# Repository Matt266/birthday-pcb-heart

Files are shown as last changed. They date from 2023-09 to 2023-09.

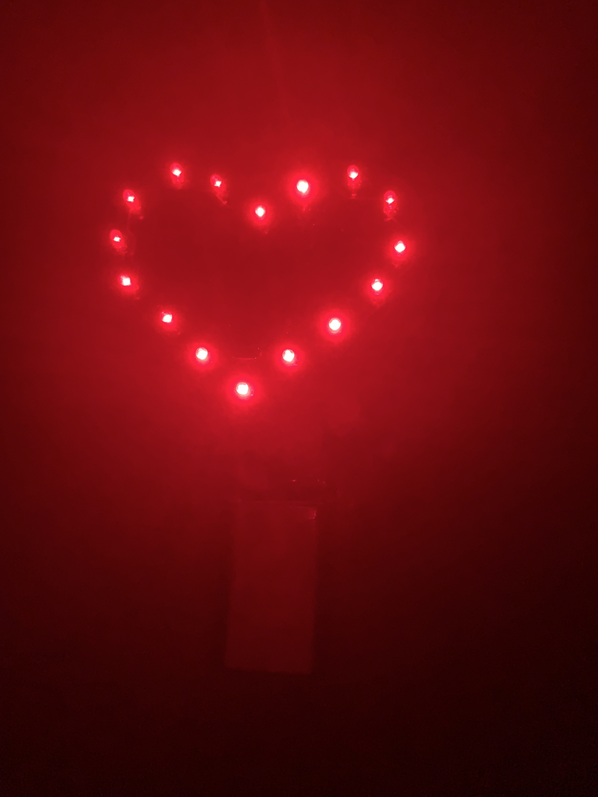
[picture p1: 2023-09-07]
Herz_Leuchten.jpg

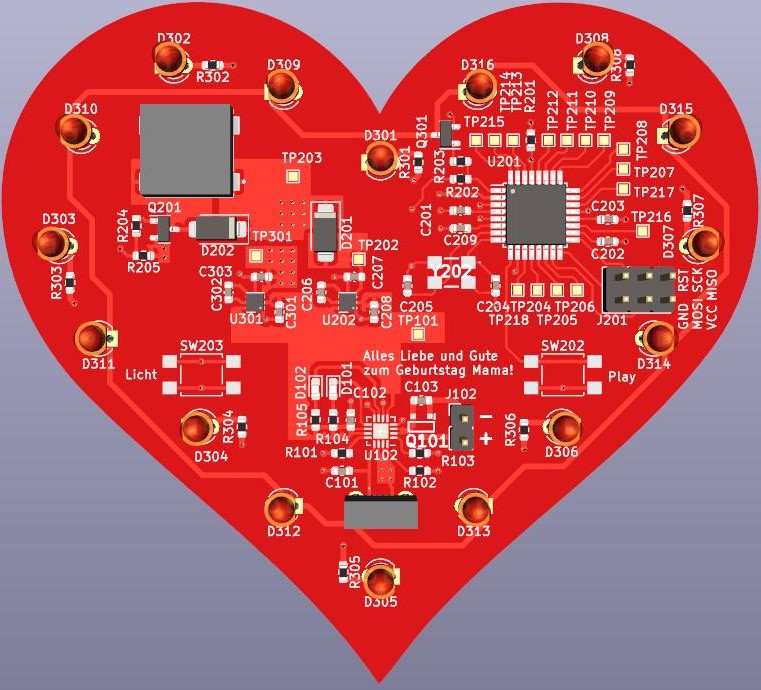
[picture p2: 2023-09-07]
MamaGeburtstag2023_3D.jpg

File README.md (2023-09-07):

# PCB Heart As Birthday Present

As birthday present for our mother my brother and I decided to create a heart-shaped PCB with a buzzer
to play "happy birthday" and LEDs to look pretty. It also should be powered by battery.

Two buttons allow cycling through brightness levels and to initiate the "happy birthday".  

<br>finished PCB<br>

## The Circuit

The exact partnumbers can be taken from the BOM and the KiCAD project. I decided to make use of a LiPo-battery for
the lower self discharge, higher capacity and possibility to recharge in comparison to regular batteries. 

A battery management ic controls charging and allowed me to add an usb connector as charging port. The PCB is also 
powered during charging. A P-Channel MOSFET protects the circuit for reverse polarity on the LiPo-Input. 

Two charge pumps step up the voltage to 5V. This made it Arduino compatible so I could more easily use an Arduino as
in circuit programmer. Also it kept the circuit smaller than inductor based boost-converter. This helped fitting all
components within the heart shape. 

The LEDs and the buzzer are controlled via N-Channel MOSFETs (one for all LEDs one for the buzzer) and connected to
PWM capable pins on the MCU.

To make it more Arduino capable and therefore ease programming for my brother I chose the classic Atmega328p as MCU. 
It was his first time programming something embedded and he did a great job! :)

## The Software

The Software was completely written by my brother (TODO: add Sketch to this repo).

## The Problems

As with all projetcs there are some things that I could have done better in the hindsight.

First of all I didn't include a switch on the PCB. I added one external switch between the LiPO-battery
and PCB afterwards but that isn't nearly as comfortable as having it included directly on the PCB.

The second problem are the charge pumps. While they get the job done they heave a massive quiescent current
and aren't really efficient.  Also running the MCU from a 5V supply voltage increased its power consumption in comparison to e.g. 3.3V.
As the voltage is stepped up the current drawn from the battery inceases even further.
This combination is responsble for a large standby current of 50mA. This massive quiescent current even makes it
unnecessary to consider putting the MCU sleeping. The current draw would remain high nonetheless.

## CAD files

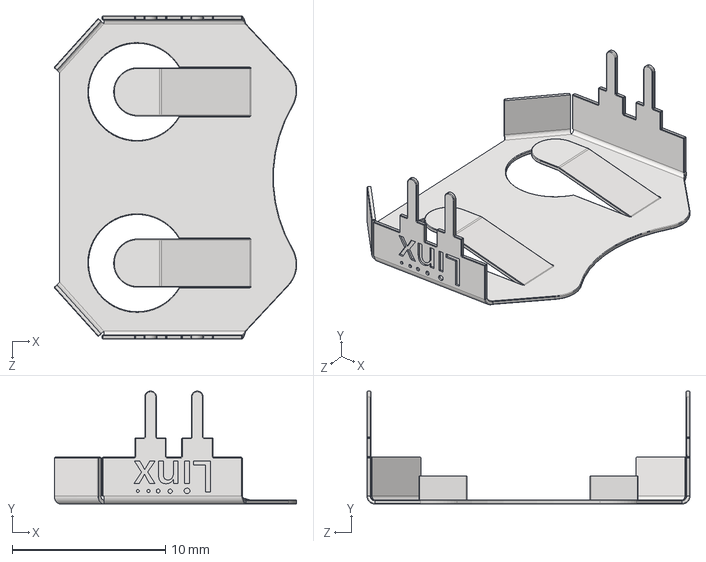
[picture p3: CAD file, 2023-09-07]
LIB_BAT-HLD-001-THM/BAT-HLD-001-THM/3D/BAT-HLD-001-THM.stp
15.8 x 7.37 x 21.1 mm

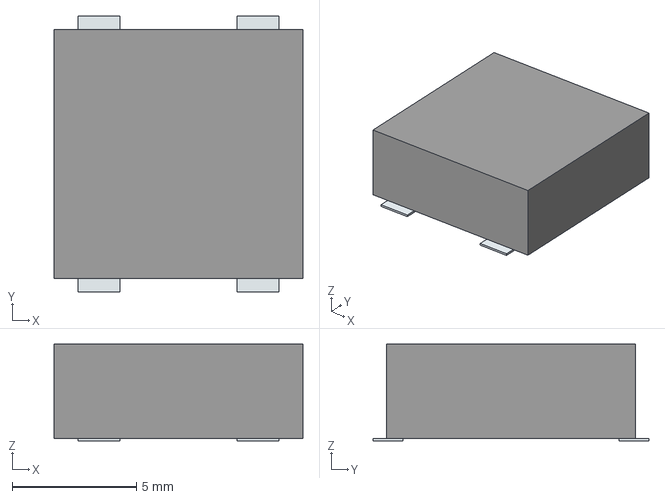
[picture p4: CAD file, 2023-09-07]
LIB_CMT-1032-85-SMT-TR/CMT-1032-85-SMT-TR/3D/CMT-1032-85-SMT-TR.stp
10.0 x 11.1 x 3.90 mm
Pins

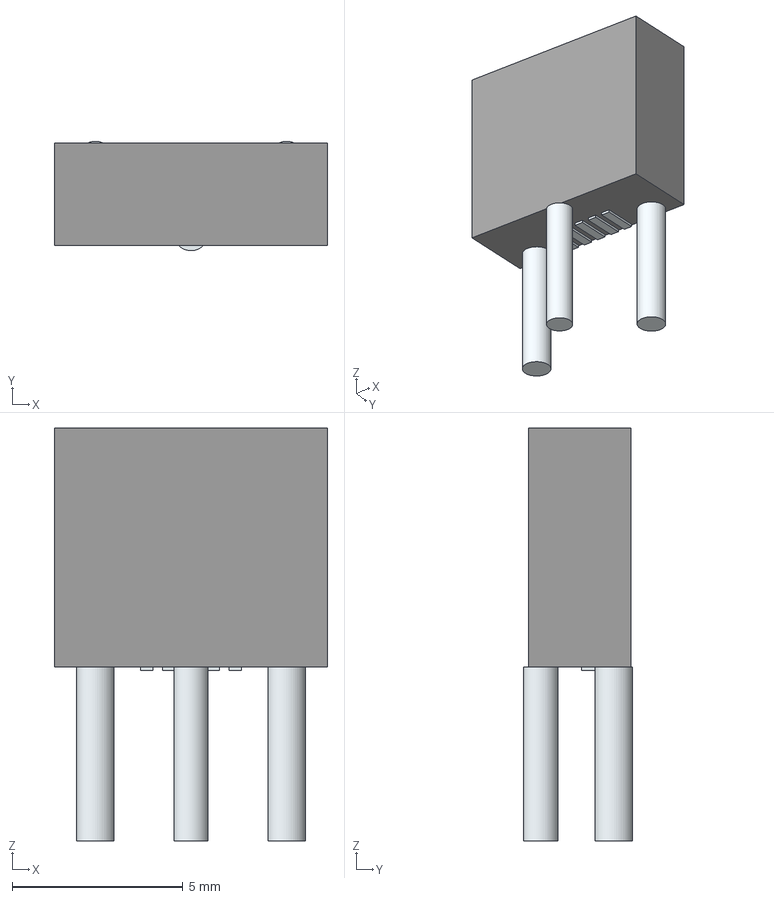
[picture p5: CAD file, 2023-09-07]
LIB_GMCB05B11124H1EU/GMCB05B11124H1EU/3D/GMCB05B11124H1EU.stp
8.00 x 3.20 x 12.1 mm
Pins
Leads

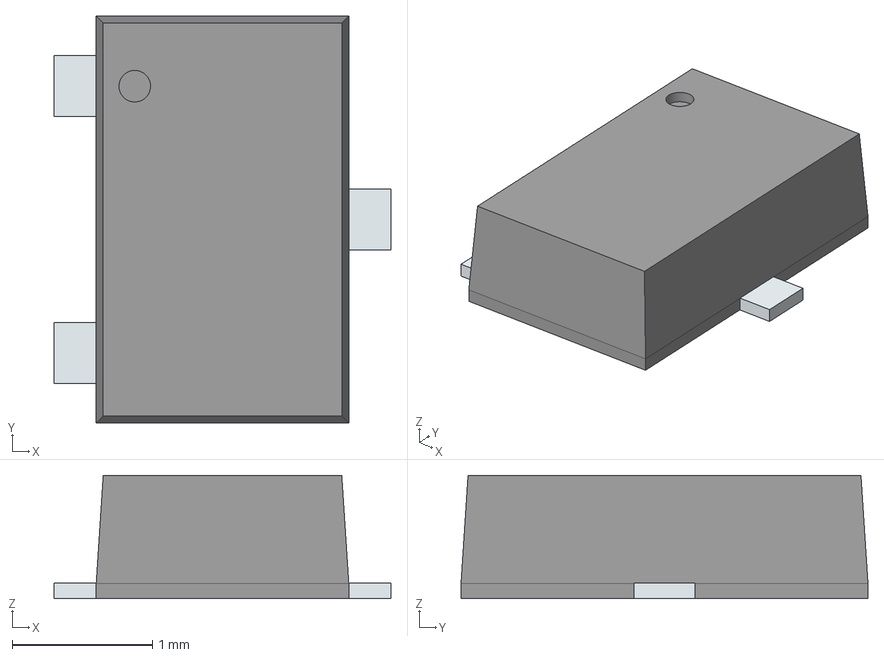
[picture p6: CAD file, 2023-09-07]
LIB_SSM3J358R,LF/SSM3J358R,LF/3D/SSM3J358R,LF.stp
2.40 x 2.90 x 0.878 mm
PinsArrayL
PinsArrayR

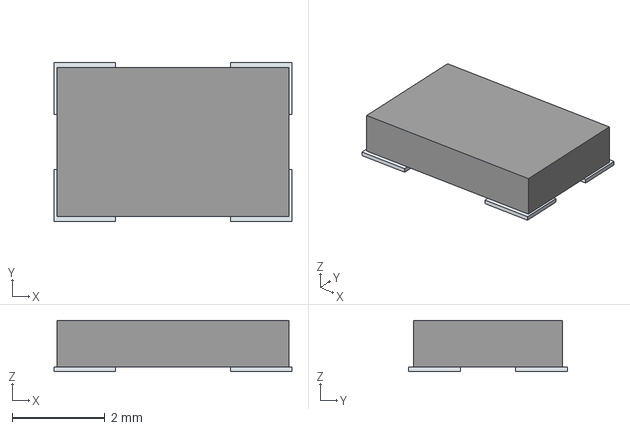
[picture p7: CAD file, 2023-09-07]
LIB_830030819/830030819/3D/830030819.stp
5.12 x 3.42 x 1.10 mm
Pins

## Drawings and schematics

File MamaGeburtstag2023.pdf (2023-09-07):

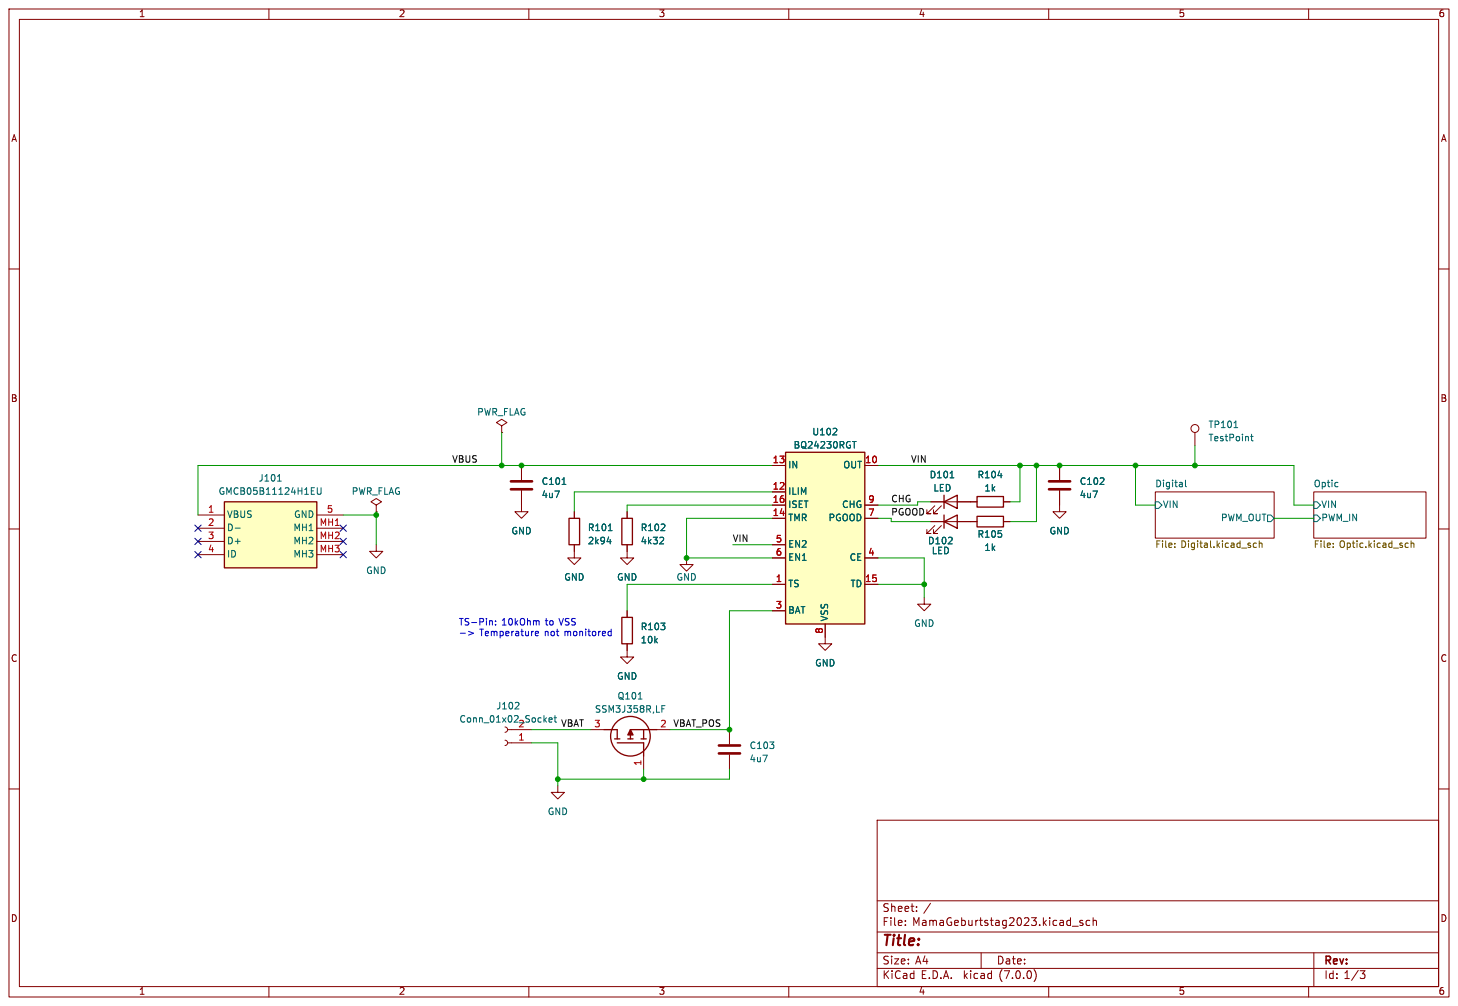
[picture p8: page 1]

PWM_IN Optic File: Optic.kicad_sch PWM_OUT VIN

TS-Pin: 10kOhm to VSS

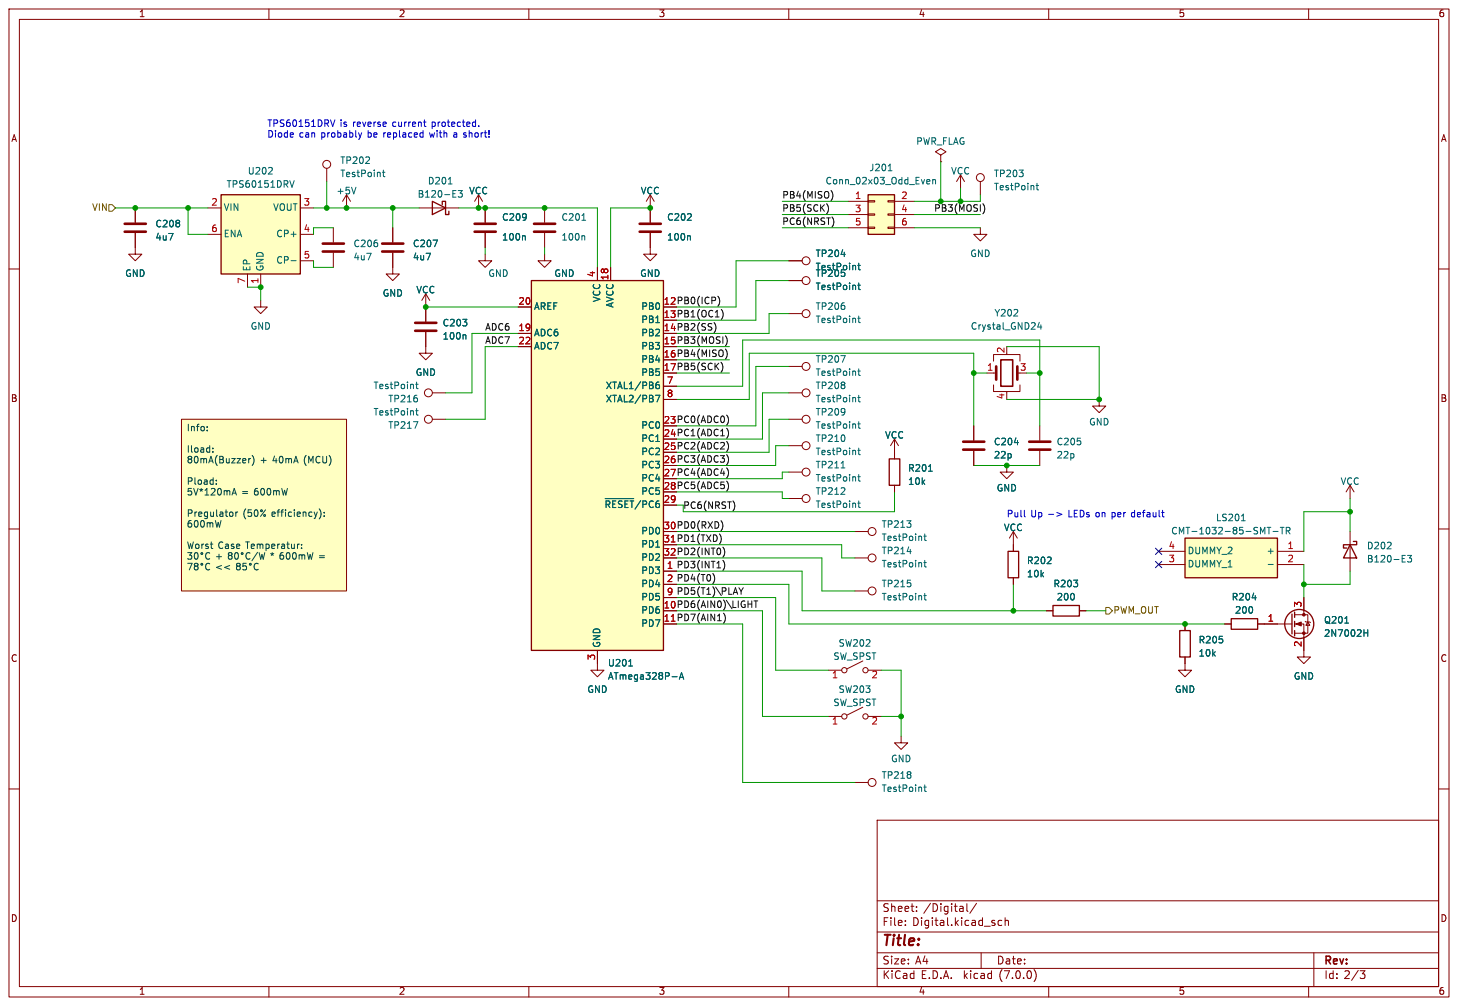
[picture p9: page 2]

1 VIN 2 VOUT 3 CP+ 4 CP- 5 ENA 6 EP

TP210 TestPoint TP211 TestPoint TP212 TestPoint GND

Id: 2/3 Title: File: Digital.kicad_sch Sheet: /Digital/

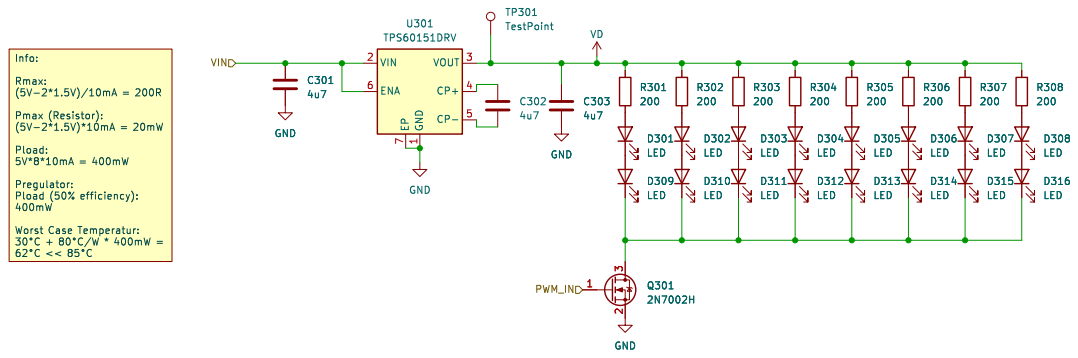
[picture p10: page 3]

1 VIN 2 VOUT 3 CP+ 4 CP- 5 ENA 6 EP

Id: 3/3 Title: File: Optic.kicad_sch Sheet: /Optic/

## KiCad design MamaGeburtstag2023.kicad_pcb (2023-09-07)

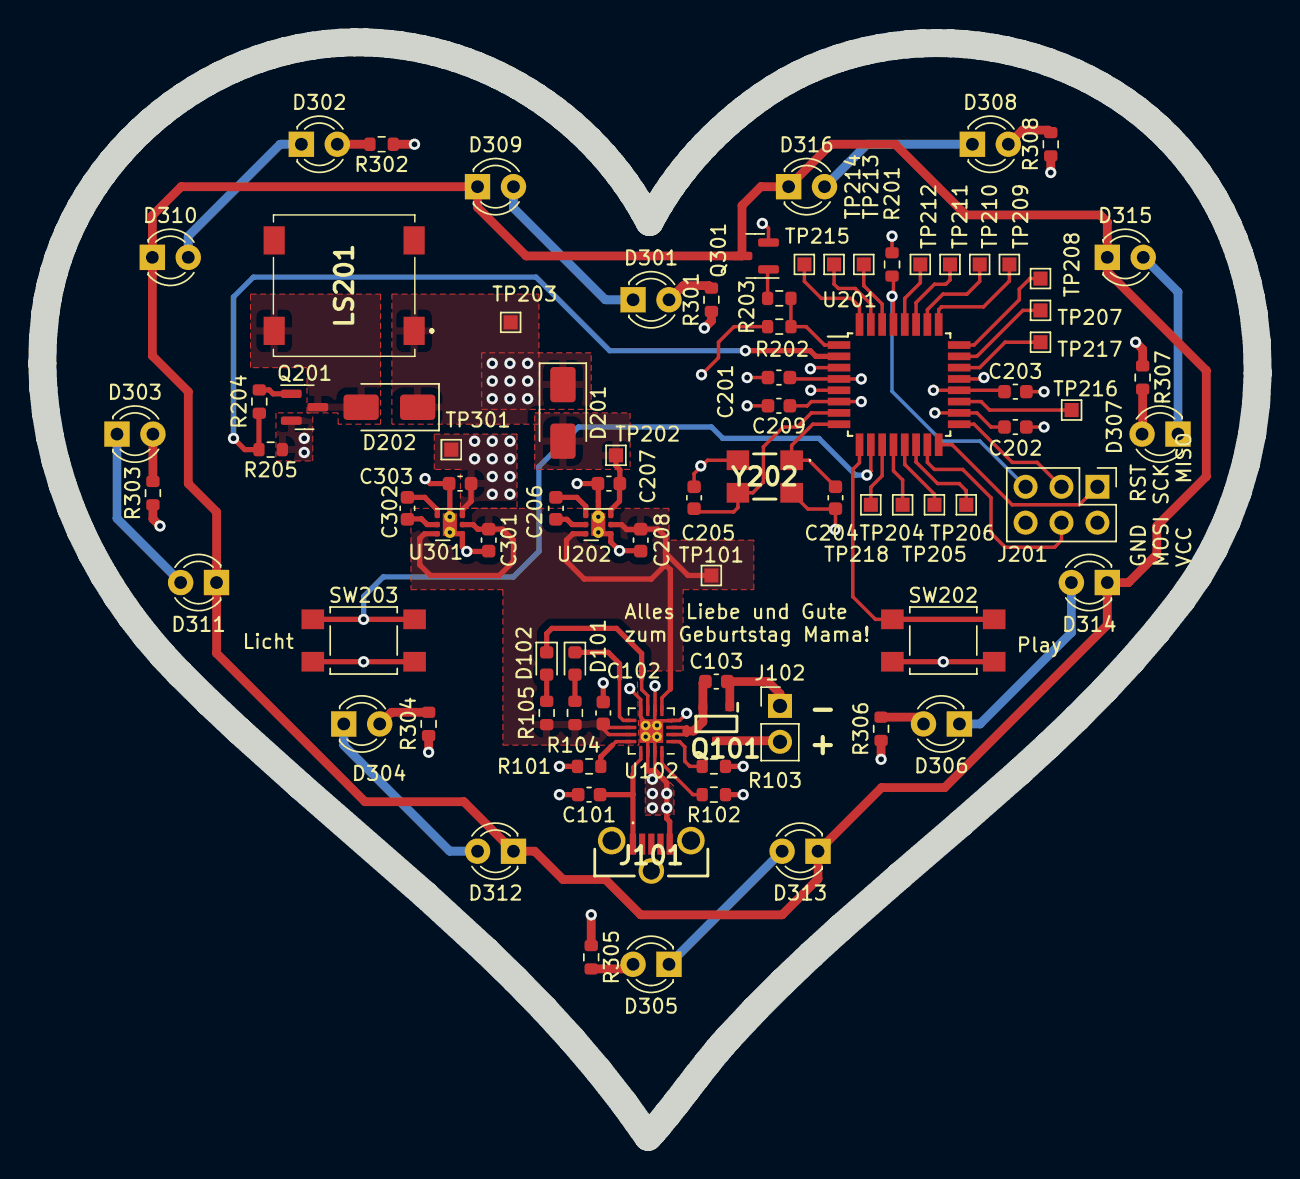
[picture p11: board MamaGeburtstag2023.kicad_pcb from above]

Board: 4 copper layers, 86.0 x 77.4 mm, 86 parts (0 on the bottom side), 64 nets.

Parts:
C101, C102, C103, C206, C207, C208, C301, C302, C303: 4u7; C_0603_1608Metric
C201, C202, C203, C209: 100n; C_0603_1608Metric
C204, C205: 22p; C_0603_1608Metric
D101, D102: LED; LED_0603_1608Metric
D201, D202: B120-E3; D_SMA
D301, D302, D303, D304, D305, D306, D307, D308, D309, D310, D311, D312, D313, D314, D315, D316: LED; LED_D3.0mm
J101: GMCB05B11124H1EU
J102: Conn_01x02_Socket; PinHeader_1x02_P2.54mm_Vertical
J201: Conn_02x03_Odd_Even; PinHeader_2x03_P2.54mm_Vertical
LS201: CMT-1032-85-SMT-TR; CMT103285SMTTR
Q101: SSM3J358R,LF; SOTFL95P240X88-3N
Q201, Q301: 2N7002H; SOT-23
R101: 2k94; R_0603_1608Metric
R102: 4k32; R_0603_1608Metric
R103, R201, R202, R205: 10k; R_0603_1608Metric
R104, R105: 1k; R_0603_1608Metric
R203, R204, R301, R302, R303, R304, R305, R306, R307, R308: 200; R_0603_1608Metric
SW202, SW203: SW_SPST; SW_SPST_TL3305A
TP101, TP202, TP203, TP204, TP205, TP206, TP207, TP208, TP209, TP210, TP211, TP212, TP213, TP214, TP215, TP216, TP217, TP218, TP301: TestPoint; TestPoint_Pad_1.0x1.0mm
U102: BQ24230RGT; VQFN-16-1EP_3x3mm_P0.5mm_EP1.68x1.68mm_ThermalVias
U201: ATmega328P-A; TQFP-32_7x7mm_P0.8mm
U202, U301: TPS60151DRV; WSON-6-1EP_2x2mm_P0.65mm_EP1x1.6mm_ThermalVias
Y202: Crystal_GND24; 830030819

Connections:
+5V: C207.1, D201.2 (A), TP202.1, U202.3 (VOUT)
/CHG: D101.1 (K), U102.9 (CHG)
/Digital/ADC6: TP216.1, U201.19 (ADC6)
/Digital/ADC7: TP217.1, U201.22 (ADC7)
/Digital/PB0(ICP): TP204.1, U201.12 (PB0)
/Digital/PB1(OC1): TP205.1, U201.13 (PB1)
/Digital/PB2(SS): TP206.1, U201.14 (PB2)
/Digital/PB3(MOSI): J201.4, U201.15 (PB3)
/Digital/PB4(MISO): J201.1, U201.16 (PB4)
/Digital/PB5(SCK): J201.3, U201.17 (PB5)
/Digital/PC0(ADC0): TP207.1, U201.23 (PC0)
/Digital/PC1(ADC1): TP208.1, U201.24 (PC1)
/Digital/PC2(ADC2): TP209.1, U201.25 (PC2)
/Digital/PC3(ADC3): TP210.1, U201.26 (PC3)
/Digital/PC4(ADC4): TP211.1, U201.27 (PC4)
/Digital/PC5(ADC5): TP212.1, U201.28 (PC5)
/Digital/PC6(NRST): J201.5, R201.1, U201.29 (~RESET/PC6)
/Digital/PD0(RXD): TP213.1, U201.30 (PD0)
/Digital/PD1(TXD): TP214.1, U201.31 (PD1)
/Digital/PD2(INT0): TP215.1, U201.32 (PD2)
/Digital/PD3(INT1): R202.1, R203.1, U201.1 (PD3)
/Digital/PD4(T0): R204.1, R205.2, U201.2 (PD4)
/Digital/PD5(T1)\PLAY: SW202.1 (A), U201.9 (PD5)
/Digital/PD6(AIN0)\LIGHT: SW203.1 (A), U201.10 (PD6)
/Digital/PD7(AIN1): TP218.1, U201.11 (PD7)
/Digital/PWM_OUT: Q301.1 (G), R203.2
/PGOOD: D102.1 (K), U102.7 (PGOOD)
/VBAT: J102.2, Q101.3 (D)
/VBAT_POS: C103.1, Q101.2 (S), U102.2 (BAT), U102.3 (BAT)
/VBUS: C101.1, J101.1 (VBUS), U102.13 (IN)
/VIN: C102.1, C208.1, C301.1, R104.1, R105.1, TP101.1, U102.5 (EN2), U102.10 (OUT), U102.11 (OUT), U202.2 (VIN), U202.6 (ENA), U301.2 (VIN), U301.6 (ENA)
GND: C101.2, C102.2, C103.2, C201.2, C202.2, C203.2, C204.2, C205.2, C207.2, C208.2, C209.2, C301.2, C303.2, J101.5 (GND), J102.1, J201.6, Q101.1 (G), Q201.2 (S), Q301.2 (S), R101.1, R102.1, R103.1, R205.1, SW202.2 (B), SW203.2 (B), U102.4 (CE), U102.6 (EN1), U102.8 (VSS), U102.14 (TMR), U102.15 (TD), U102.17 (VSS), U201.3 (GND), U201.5 (GND), U201.21 (GND), U202.1 (GND), U202.7 (EP), U301.1 (GND), U301.7 (EP), Y202.2, Y202.4
unnamed: D101.2 (A), R104.2
unnamed: D102.2 (A), R105.2
unnamed: D202.2 (A), LS201.2 (-), Q201.3 (D)
unnamed: D301.2 (A), R301.2
unnamed: D301.1 (K), D309.2 (A)
unnamed: D302.2 (A), R302.2
unnamed: D302.1 (K), D310.2 (A)
unnamed: D303.2 (A), R303.2
unnamed: D303.1 (K), D311.2 (A)
unnamed: D304.2 (A), R304.2
unnamed: D304.1 (K), D312.2 (A)
unnamed: D305.2 (A), R305.2
unnamed: D305.1 (K), D313.2 (A)
unnamed: D306.2 (A), R306.2
unnamed: D306.1 (K), D314.2 (A)
unnamed: D307.2 (A), R307.2
unnamed: D307.1 (K), D315.2 (A)
unnamed: D308.2 (A), R308.2
unnamed: D308.1 (K), D316.2 (A)
unnamed: D309.1 (K), D310.1 (K), D311.1 (K), D312.1 (K), D313.1 (K), D314.1 (K), D315.1 (K), D316.1 (K), Q301.3 (D)
unnamed: Q201.1 (G), R204.2
unnamed: R101.2, U102.12 (ILIM)
unnamed: R102.2, U102.16 (ISET)
unnamed: R103.2, U102.1 (TS)
unnamed: C205.1, U201.7 (XTAL1/PB6), Y202.3
unnamed: C204.1, U201.8 (XTAL2/PB7), Y202.1
unnamed: C206.1, U202.4 (CP+)
unnamed: C206.2, U202.5 (CP-)
unnamed: C302.1, U301.4 (CP+)
unnamed: C302.2, U301.5 (CP-)
VCC: C201.1, C202.1, C203.1, C209.1, D201.1 (K), D202.1 (K), J201.2, LS201.1 (+), R201.2, R202.2, TP203.1, U201.4 (VCC), U201.6 (VCC), U201.18 (AVCC), U201.20 (AREF)
VD: C303.1, R301.1, R302.1, R303.1, R304.1, R305.1, R306.1, R307.1, R308.1, TP301.1, U301.3 (VOUT)
